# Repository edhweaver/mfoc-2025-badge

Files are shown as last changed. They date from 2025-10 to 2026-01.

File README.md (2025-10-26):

# mfoc-2025-badge

This repo contains the Design Files and supporting documentation for the Maker Faire Orange County 2025 Badge.
* maker-faire-badge.kicad_pro - KiCad Project File
* maker-faire-badge.kicad_prb - KiCad Layout File
* maker-faire-badge.kicad_sch - KiCad Schematic File
* Library.pretty\ - contains all footprints artwork
* Manufacturing Files
  * PCB-maker-faire-badge-Rev_X.zip - Printed Circuit Board Artwork and Fabrication Files
  * ASSEMBLY-maker-faire-badge-Rev_X.zip - PCB Assembly Files (Bill of Materials and Assembly Documentation)
* README.mk - this file
* CHANGES.txt - Change log of modifications from prior published design as required by the CERN-OHL-S license
* cern_ohl_s_v2_user_guide.txt - User Guide for the CERN-OHL-S license
* LICENSES\ - contains all project licenses

## License Information

The MFOC 2025 Badge hardware and all documentation in this repository are licensed under the CERN Open Hardware License, strongly reciprocal, v2.0 or later (CERN-OHL-S-2.0).

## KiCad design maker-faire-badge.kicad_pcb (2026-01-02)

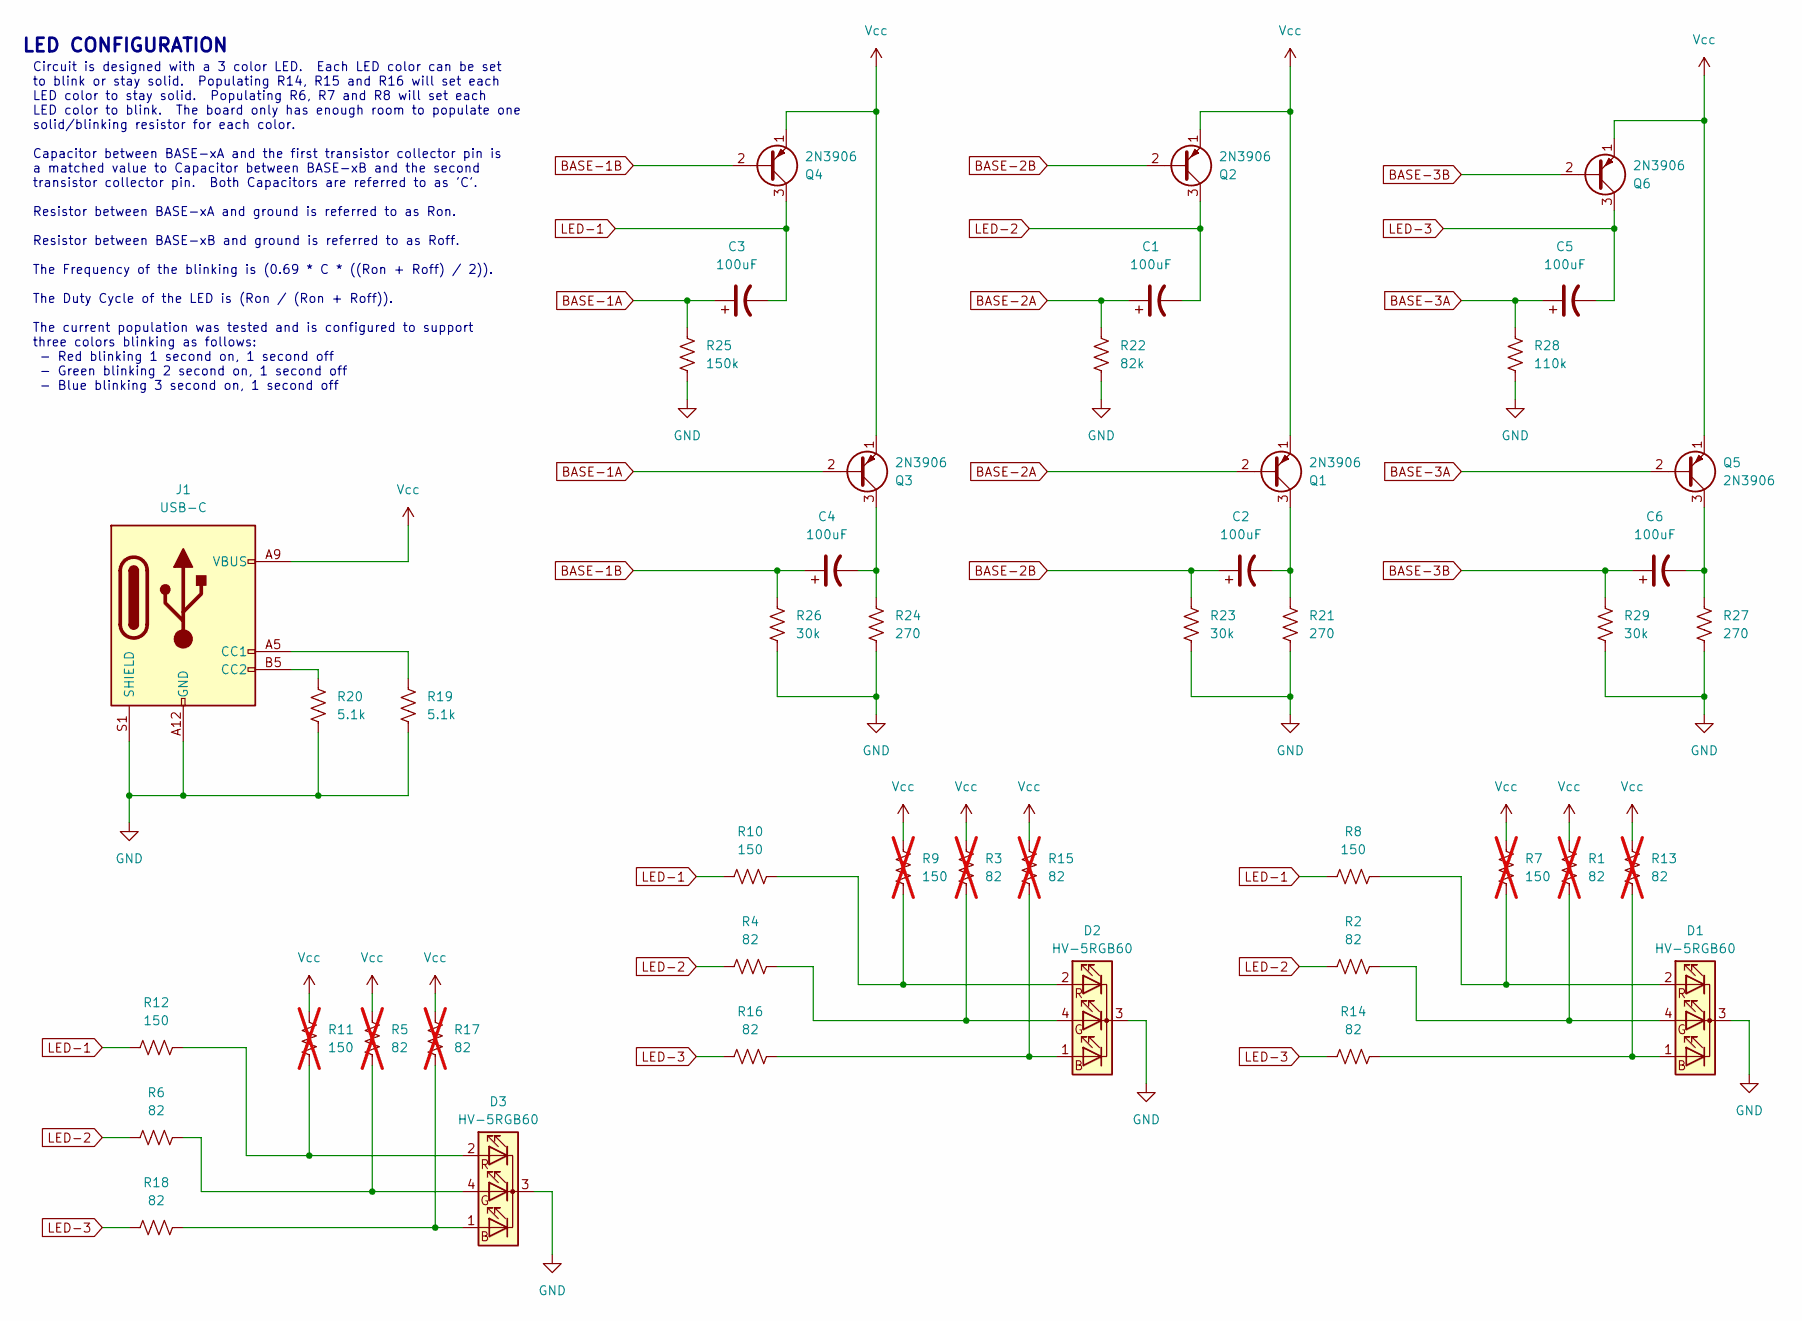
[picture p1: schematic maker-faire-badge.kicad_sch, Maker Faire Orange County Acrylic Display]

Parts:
C1, C2, C3, C4, C5, C6: 100uF; CP_Radial_D5.0mm_P2.50mm; PartNumber ECA-1CM101I
D1, D2, D3: HV-5RGB60; LED_D5.0mm-4_RGB_Wide_Pins; PartNumber HV-5RGB60
J1: USB-C; USB_C_Receptacle_GCT_USB4135-GF-A_6P_TopMnt_Horizontal; PartNumber 10174819-00011LF
Q1, Q2, Q3, Q4, Q5, Q6: 2N3906; TO-92_Inline_Wide; PartNumber 2N3906TFR
R1, R3, R5, R13, R15, R17: 82; R_Axial_DIN0207_L6.3mm_D2.5mm_P2.54mm_Vertical; PartNumber CFR-25JB-52-82R; not fitted
R2, R4, R6, R14, R16, R18: 82; R_Axial_DIN0207_L6.3mm_D2.5mm_P2.54mm_Vertical; PartNumber CFR-25JB-52-82R
R7, R9, R11: 150; R_Axial_DIN0207_L6.3mm_D2.5mm_P2.54mm_Vertical; PartNumber CFR-25JB-52-150R; not fitted
R8, R10, R12: 150; R_Axial_DIN0207_L6.3mm_D2.5mm_P2.54mm_Vertical; PartNumber CFR-25JB-52-150R
R19, R20: 5.1k; R_Axial_DIN0207_L6.3mm_D2.5mm_P2.54mm_Vertical; PartNumber CFR-25JB-52-5K1
R21, R24, R27: 270; R_Axial_DIN0207_L6.3mm_D2.5mm_P2.54mm_Vertical; PartNumber CFR-25JB-52-270R
R22: 82k; R_Axial_DIN0207_L6.3mm_D2.5mm_P2.54mm_Vertical; PartNumber CFR-25JB-52-82k
R23, R26, R29: 30k; R_Axial_DIN0207_L6.3mm_D2.5mm_P2.54mm_Vertical; PartNumber CFR-25JB-52-30K
R25: 150k; R_Axial_DIN0207_L6.3mm_D2.5mm_P2.54mm_Vertical; PartNumber CFR-25JB-52-150K
R28: 110k; R_Axial_DIN0207_L6.3mm_D2.5mm_P2.54mm_Vertical; PartNumber CFR-25JB-52-110K

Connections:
BASE-1A: C3.1, Q3.2 (B), R25.2
BASE-1B: C4.1, Q4.2 (B), R26.2
BASE-2A: C1.1, Q1.2 (B), R22.2
BASE-2B: C2.1, Q2.2 (B), R23.2
BASE-3A: C5.1, Q5.2 (B), R28.2
BASE-3B: C6.1, Q6.2 (B), R29.2
GND: D1.3 (K), D2.3 (K), D3.3 (K), J1.A12 (GND), J1.B12 (GND), J1.S1 (SHIELD), R19.1, R20.1, R21.1, R22.1, R23.1, R24.1, R25.1, R26.1, R27.1, R28.1, R29.1
LED-1: C3.2, Q4.3 (C), R8.2, R10.2, R12.2
LED-2: C1.2, Q2.3 (C), R2.2, R4.2, R6.2
LED-3: C5.2, Q6.3 (C), R14.2, R16.2, R18.2
unnamed: D1.1 (BA), R13.1, R14.1
unnamed: D1.4 (GA), R1.1, R2.1
unnamed: D1.2 (RA), R7.1, R8.1
unnamed: D2.1 (BA), R15.1, R16.1
unnamed: D2.4 (GA), R3.1, R4.1
unnamed: D2.2 (RA), R9.1, R10.1
unnamed: D3.1 (BA), R17.1, R18.1
unnamed: D3.4 (GA), R5.1, R6.1
unnamed: D3.2 (RA), R11.1, R12.1
unnamed: J1.A5 (CC1), R19.2
unnamed: J1.B5 (CC2), R20.2
unnamed: C2.2, Q1.3 (C), R21.2
unnamed: C4.2, Q3.3 (C), R24.2
unnamed: C6.2, Q5.3 (C), R27.2
Vcc: J1.A9 (VBUS), J1.B9 (VBUS), Q1.1 (E), Q2.1 (E), Q3.1 (E), Q4.1 (E), Q5.1 (E), Q6.1 (E), R1.2, R3.2, R5.2, R7.2, R9.2, R11.2, R13.2, R15.2, R17.2

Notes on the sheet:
Circuit is designed with a 3 color LED. Each LED color can be set to blink or stay solid. Populating R14, R15 and R16 will set each LED color to stay solid. Populating R6, R7 and R8 will set each LED color to blink. The board only has enough room to populate one solid/blinking resistor for each col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
LED CONFIGURATION

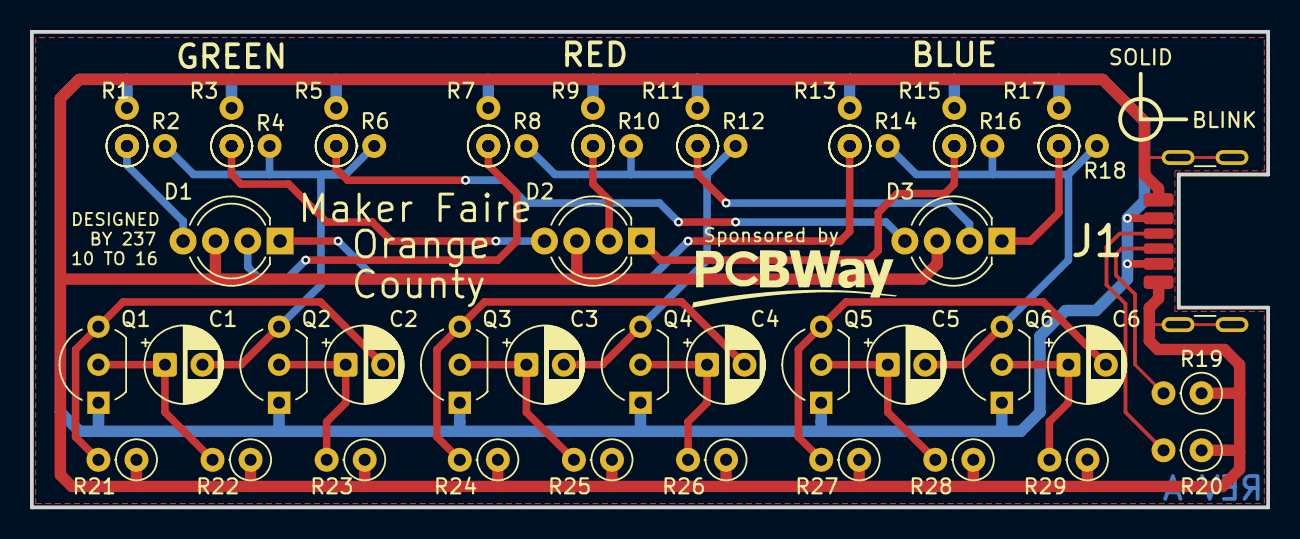
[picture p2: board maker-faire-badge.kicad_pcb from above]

Board: 2 copper layers, 82.6 x 31.7 mm, 45 parts (0 on the bottom side), 25 nets.

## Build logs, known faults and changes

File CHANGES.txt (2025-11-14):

SPDX-FileCopyrightText: 2025 Ed Weaver <ed.h.weaver@gmail.com>
SPDX-License-Identifier: CERN-OHL-S-2.0+

## 2025-11-02 - Acrylic Display - Revision A
- **Modified by:** Ed Weaver
- **Description:** Updated to 3 LEDs, Updated power to only USB C (No Batteries)
- **Relevant Files:** `maker-faire-badge.kicad_pro`, `maker-faire-badge.kicad_pcb`, `maker-faire-badge.kicad_sch`

## 2025-07-28 - Revision C
- **Modified by:** Ed Weaver
- **Description:** Component Placement updates to reflect optimal component placement
- **Relevant Files:** `maker-faire-badge.kicad_pro`, `maker-faire-badge.kicad_pcb`, `maker-faire-badge.kicad_sch`

## 2025-07-20 - Revision B
- **Modified by:** Ed Weaver
- **Description:** Silkscreen updates to reflect optimal component placement
- **Relevant Files:** `maker-faire-badge.kicad_pro`, `maker-faire-badge.kicad_pcb`, `maker-faire-badge.kicad_sch`

## 2025-07-05 - Initial Release
- **Modified by:** Ed Weaver
- **Description:** Initial Revision of the MFOC 2025 Badge
- **Relevant Files:** `maker-faire-badge.kicad_pro`, `maker-faire-badge.kicad_pcb`, `maker-faire-badge.kicad_sch`

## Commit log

2025-10-26 User/ed cleanup (#1)
    * Added Design files for Revision A
    * Add Manufacturer files for Revision A
    * Added License information
    [maker-faire-badge.kicad_pcb, maker-faire-badge.kicad_sch]
2025-10-26 User/ed cleanup (#2)
    * Updated Library components
    * Updated Silkscreen on Layout
    * Added manufacturing files
    [maker-faire-badge.kicad_pcb, maker-faire-badge.kicad_sch]
2025-10-27 MFOC 2025 Boards - Revision C
    * Updated Change Log
    * Updated Change Log
    * Added Manufacturing Files
    * updated design files
    * updated schematic title block
    * new manufacturing informaiton
    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
    [maker-faire-badge.kicad_pcb, maker-faire-badge.kicad_sch]
2025-11-14 Initial design if Acylic Display PCBA
    [maker-faire-badge.kicad_pcb, maker-faire-badge.kicad_sch]
2026-01-02 BOM and Fabrication Note corrections
    [maker-faire-badge.kicad_pcb, maker-faire-badge.kicad_sch]
